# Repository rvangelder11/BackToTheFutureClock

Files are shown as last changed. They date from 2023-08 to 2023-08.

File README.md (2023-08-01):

# Back To The Future Clock
Based on <https://www.thingiverse.com/thing:5916251>



I modified the design of the parts to fit to my printer and added openings to be able to accomodate a flatcable.
I designed a PCB that can be used for all three levels by chosing the correctc onnector.
I connected the 3 PCB's with a floppy disk flatcablew that I have in ample supply from various computers

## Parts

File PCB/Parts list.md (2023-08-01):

# Parts list

- 1x ESP32-S2 (AliExpress) solder 4x 8 pins to it
- 1x two position switch 5 mm (AliExpress)
- 1 DC-005 PCB mount 5.5x2.1 mm female power connector (AliExpress)
- 1x red alphanumeric 4 digit display 0.54 inch red HT16K33 I2C (AliExpress)
- 1x Quad Alphanumeric Display - Yellow 0.54 inch Digits w/ I2C Backpack Adafruit 2158 (vanAllesenMeer) Please Note: AliExpress has this in orange, but that does not fit the yellow numeric displays
- 1x Quad Alphanumeric Display -Yellow-Green 0.54 inch Digits w/ Backpack Adafruit 2159 (vanAllesenMeer) Please Note: AliExpress has this in green, but that does not fit the green numeric displays
- 3x TM1637 Led Display Module 4 Digit 7 Segment 0.56 Inch Green (AliExpress)
- 3x TM1637 Led Display Module 4 Digit 7 Segment 0.56 Inch Red (AliExpress)
- 3x TM1637 Led Display Module 4 Digit 7 Segment 0.56 Inch Yellow (AliExpress)
- 1x LM 2596 buck conveter (set to 5V output) (AiliExpress)
- power supply around 9V, 200 mA or more, with a 5.5/2.1 male plug (AliExpress)
- 110 or more pin headers (AliExpress)

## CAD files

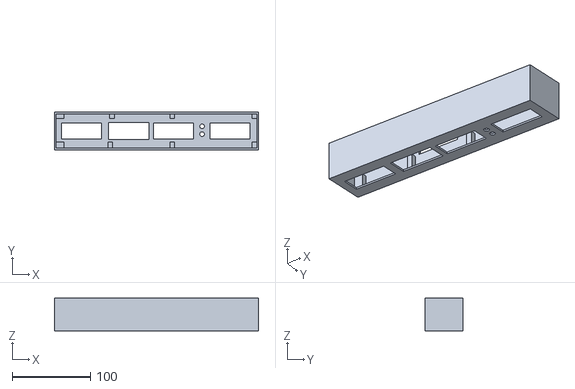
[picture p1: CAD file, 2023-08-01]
3D parts/BTTF front top v3.stl
261.0 x 48.0 x 42.0

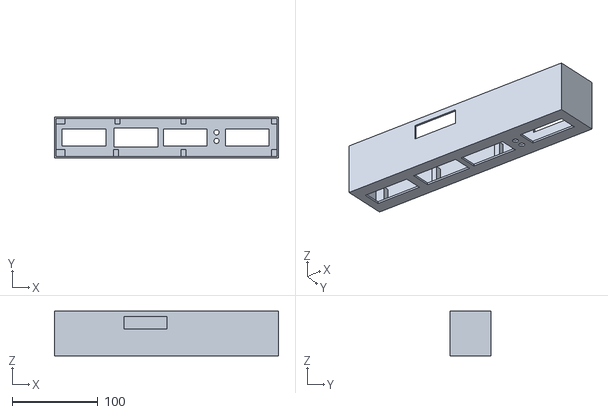
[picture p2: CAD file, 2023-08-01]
3D parts/BTTF front middle v8.stl
261.0 x 48.0 x 52.0

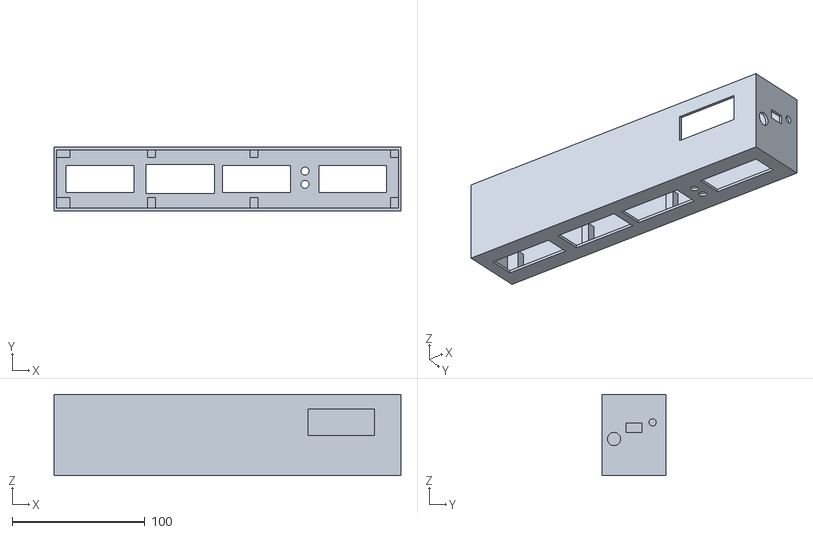
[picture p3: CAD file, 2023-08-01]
3D parts/BTTF front bottom v7.stl
261.0 x 48.0 x 61.0

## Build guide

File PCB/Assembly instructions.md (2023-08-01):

# Assembly instructions

- Print the 3D parts. On my Ender 3 it just fitted if I printed it at almost 45 degrees without a skirt.
- Glue the pieces together (I used Bisontix, but other glue might work as well).
- The bottom part has a tight fit, to prevent falling out.

PCB_PCB_BTTF print_2_2023-05-01

Schematic_BTTF print_2023-05-01

The PCB is suitable for all three levels. By connecting to the right connector, the right LED signals are transfered.

- The bottom level PCB needs to be populated with the power connector DC1, femail pin headers for the microcomputer ESP32-S2 (assuming that the microcomputer contains the female pins). In my version of the PCB, these pins were a bit to close together, so the ESP32 needed a little squeeze to fit. 
- each PCB contains on the frontside (the side that shows "LED Display" and "Segment") from left to right: two 4 digit numeric display, a 4 digit alphanumeric display and one 4 digit display. The 4 digit displays have 4 pins on each side. The female part is mounted on the PCB, the male part on the display. The alphanumeric display has 5 pins on the top, again with pins on the display side and female parts on the PCB side.
- The bottom PC contains all displays in Orange
- AM and PM leds are between the two left 4 digit displays. Resistor value 330 ohm.
- For the bottom PC, 2x17 pins need to be soldered on the backside of the PC at the location indicated with "ALL". the two left most round holes are not used
- Also on on the backside, an LM2596 buck converter needs to be mounted to reduce the incoming voltage. Before anything else is connected, check whether the output voltage is 5V
- The middle PCB is only populated with the yellowgreen displays, resistors and green LEDS  and on the backside with 2x18 pins on the position indicated with "GREEN"
- The top PCB is only populated with the red displays and on the backside with 2x17 pins on the position indicated with "GREEN". the two left most round holes are not used
- I have added a switch to be able to swith between 3.3V or 5V to the numeric displays. I found that it needs to be at 3.3V at startup. When all displays are on (and the time is synchronised) you can switch to 5V to have the right brightness. The switch is wired to the bottom PC at location indicated with S1

## With the flatcable connected



## Without the flatcable



I have added 100 nF decoupling capacitors at the power supply of each display to prevent erattic behaviour of the displays

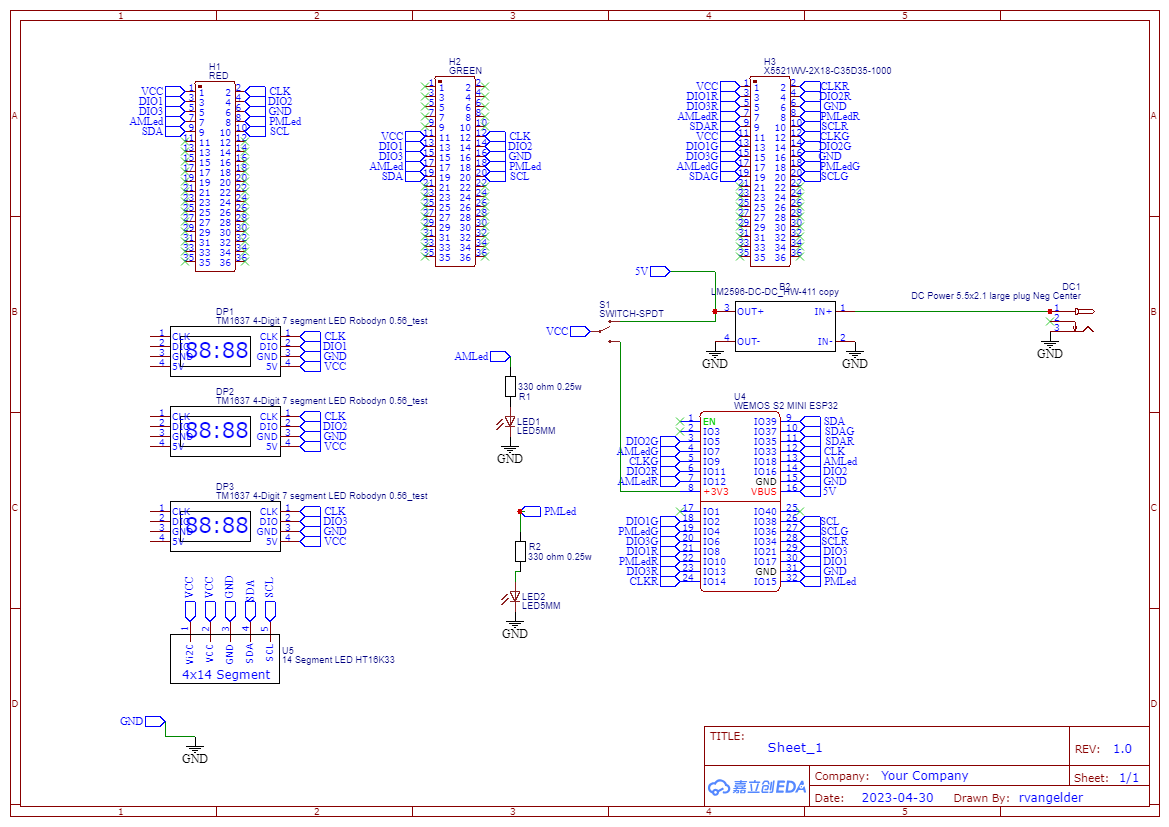
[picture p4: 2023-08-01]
PCB/Schematic_BTTF print_2023-05-01.png

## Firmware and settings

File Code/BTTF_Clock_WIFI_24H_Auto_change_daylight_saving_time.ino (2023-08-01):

#include <Arduino.h>
#include <TM1637Display.h>         // for the 7 segment DIO CLK displays
#include <WiFiManager.h>           // to make an AP if no WiFo connection is found
#include <ezTime.h>                // set NL time and DST
#include <NTPClient.h>             // for NTP Time
#include <Wire.h>                  // for I2C connection
#include <Adafruit_LEDBackpack.h>  // for alphanumeric I2C displays

// Module connection pins (Digital Pins)
#define red_CLK 14
#define red1_DIO 8
#define red2_DIO 11
#define redPMa 12  // original output has a defect
#define redAMa 10  // original output has a defect
#define redPMb 34
#define redAMb 35
#define red3_DIO 13

#define green_CLK 9
#define green1_DIO 2
#define green2_DIO 5
#define greenPM 7
#define greenAM 4
#define green3_DIO 6

#define orange_CLK 33
#define orange1_DIO 17
#define orange2_DIO 16
#define orangePM 18
#define orangeAM 15
#define orange3_DIO 21

#define SDA 39
#define SCL 38

bool WifiConnected = false;

//Set the red displays
int red_day = 4;
int red_month = 11;
int red_year = 2027;

//set the orange displays
int orange_day = 4;
int orange_month = 11;
int orange_year = 1960;

char* HostName = "BTTFclock";
//=====================================================================
Timezone myTZ;
TwoWire I2Cmonth = TwoWire(0);  //define I2C to be able to define non-standard pins

TM1637Display green1(green_CLK, green1_DIO);
TM1637Display green2(green_CLK, green2_DIO);
TM1637Display green3(green_CLK, green3_DIO);

TM1637Display red1(red_CLK, red1_DIO);
TM1637Display red2(red_CLK, red2_DIO);
TM1637Display red3(red_CLK, red3_DIO);

TM1637Display orange1(orange_CLK, orange1_DIO);
TM1637Display orange2(orange_CLK, orange2_DIO);
TM1637Display orange3(orange_CLK, orange3_DIO);

Adafruit_AlphaNum4 MonthRed = Adafruit_AlphaNum4();
Adafruit_AlphaNum4 MonthGreen = Adafruit_AlphaNum4();
Adafruit_AlphaNum4 MonthOrange = Adafruit_AlphaNum4();

void setup() {
  Serial.begin(115200);
  delay(5000);  // wait long enough to switch over to serial monitor
  Serial.println();

  I2Cmonth.begin(SDA, SCL, 100000);  // set non standard I2C pins. see defines
  MonthRed.begin(0x70, &I2Cmonth);   // refer to non-std I2C pins
  MonthGreen.begin(0x71, &I2Cmonth);
  MonthOrange.begin(0x72, &I2Cmonth);
  MonthGreen.setBrightness(12);  // reduce brightness of emerald alphanumeric display as it is brighter than red and orange,
  MonthOrange.setBrightness(2);
  MonthRed.setBrightness(15);
  Serial.println("Connecting");
  connectWiFi();  // start WiFi connection brings up an A/P on 192.168.4.1 on accesspoint with the name as set in  <HostName>

  analogWriteResolution(6);  // set resolution to 6 bits = 0-63
  red1.clear();              // left two positions need to remain blank
  red1.setBrightness(2);     // red needs to be set very low to compare with green
  red2.setBrightness(2);
  red3.setBrightness(2);

  green1.clear();           // left two positions need to remain blank
  green1.setBrightness(7);  // green is on max brightness
  green2.setBrightness(7);
  green3.setBrightness(7);

  orange1.clear();           // left two positions need to remain blank
  orange1.setBrightness(3);  // orange needs to be set to compare with green
  orange2.setBrightness(3);
  orange3.setBrightness(3);
  unsigned long millis_since_start = millis();
  while (!waitForSync(20)) Serial.println("Reconnecting...");
  Serial.println("time synced");
  Serial.print("it took: ");
  unsigned long delta = millis() - millis_since_start;
  Serial.print(delta);
  Serial.println(" ms");
  Serial.println(myTZ.dateTime("H:i:s"));
  //if (!myTZ.setCache(0))
  myTZ.setLocation(F("nl"));  // set to Dutch time incl DST
}
int oldminute = 60;  // to be sure that there will be a difference at start
int newminute;
byte pattern;
void loop() {
  events(); // to enable timesyncing
  newminute = myTZ.minute();
   orange3.showNumberDecEx(myTZ.second(), pattern, true, 4, 0);
  if (newminute != oldminute) {
    oldminute = newminute;
    //((MyTZ.second() % 2) == 0) ? pattern = 0b01000000 : pattern = 0b00000000;
    pattern = 0b01000000;
    Serial.print("Time: ");
    Serial.println(myTZ.dateTime("d-M-Y H:i:s"));

    red1.showNumberDecEx(red_day, 0b01000000, false, 2, 1);  //0b01000000 is with colon, leading zero = true, length = 2, pos = 0 (start at left most digit)
    DisplayMonth(MonthRed, red_month);                       // Month in text via I2C
    red2.showNumberDecEx(red_year, 0b00000000, true);        //0b00000000 is without colon
    red3.showNumberDecEx(myTZ.hour(), pattern, true, 2, 0);
    red3.showNumberDecEx(myTZ.minute(), pattern, true, 2, 2);
    AMPM(redAMa, redPMa, myTZ.hour(), 12);
    AMPM(redAMb, redPMb, myTZ.hour(), 12);  //pin 10 and 12 have become NC 10 is connected to 35 and 12 is connected to 34

    green1.showNumberDecEx(myTZ.day(), 0b01000000, false, 2, 1);
    DisplayMonth(MonthGreen, myTZ.month());  // Month in text via I2C
    green2.showNumberDecEx(myTZ.year(), 0b00000000, true);
    green3.showNumberDecEx(myTZ.hour(), pattern, true, 2, 0);
    green3.showNumberDecEx(myTZ.minute(), pattern, true, 2, 2);
    AMPM(greenAM, greenPM, myTZ.hour(), 40);

    orange1.showNumberDecEx(orange_day, 0b01000000, false, 2, 1);
    DisplayMonth(MonthOrange, orange_month);  // Month in text via I2C
    orange2.showNumberDecEx(orange_year, 0b00000000, true);
    orange3.showNumberDecEx(myTZ.hour(), pattern, true, 2, 0);
    orange3.showNumberDecEx(myTZ.minute(), pattern, true, 2, 2);
    AMPM(orangeAM, orangePM, myTZ.hour(), 6);
  }
}

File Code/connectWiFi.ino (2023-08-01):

void connectWiFi() {
  //WiFi.mode(WIFI_STA);                  // explicitly set mode, esp defaults to STA+AP
  WiFiManager wm;                       // WiFiManager to start as AP to enter WiFi credentials
  wm.setCountry("US");                  // default is china, they have other WiFi channels
  bool res = wm.autoConnect(HostName);  // open AP
  if (!res) {
    Serial.println("Failed to connect");
    WifiConnected = false;
    WiFi.mode(WIFI_AP);  //Set AccessPoint only
    delay(2000);
    bool succes = WiFi.softAP("BTCC_AP");
    if (succes) Serial.println("WiFi Ready");
    else Serial.println("WiFi failed");
    delay(250);
    Serial.print("Soft-AP IP address = ");
    Serial.println(WiFi.softAPIP());
  } else {
    Serial.println("connected...yeey :)");  // if you get here you have connected to the WiFi
    delay(500);
    Serial.println("");
    Serial.print("Connected to WiFi network with IP Address: ");
    Serial.println(WiFi.localIP());
    Serial.println(WiFi.macAddress());
    WifiConnected = true;
  }
  delay(200);
  if (WifiConnected) {
    Serial.println("Wait for time sync");  // for accurate clock:
    while (!waitForSync(20)) Serial.println("Reconnecting...");
    Serial.println("time synced");
    Serial.println(myTZ.dateTime("H:i:s"));
    if (!myTZ.setCache(0)) myTZ.setLocation(F("nl"));  // set to Dutch time incl DST
  }
}

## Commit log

2023-08-01 initial upload
    [BTTF front bottom v7.stl, BTTF front middle v8.stl, BTTF front top v3.stl]
2023-08-01 Rename Assemply instructions.md to Assembly instructions.md
2023-08-01 Update Assembly instructions.md
